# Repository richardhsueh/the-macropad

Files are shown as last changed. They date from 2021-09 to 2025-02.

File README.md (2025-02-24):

# The Macropad

## Overview
A custom design Macropad with 9 buttons
Macropad

## Features
- hot-swappable switches 
- hot-swappable micro controller
- minimal construction for easy repair

## Project Structure
```
project/
├── firmware/          # MCU code if applicable
├── pcb/               # Gerber files for manufacturing the main pcb
└── plate/             # Gerber files for manufacturing the top plate

```

## Requirements
- KiCad 7.0+
- VScode

## Manufacturing
Gerber files are provided in `pcb/` and `plate/`. Recommended fab specs:
- Layers: 2
- Thickness: 1.6mm
- Copper weight: 1oz
- Surface finish: HASL/ENIG

## Assembly
Macropad Assembly

1. Solder the hot-swap sockets to the PCB
2. Insert the switches into the top plate
3. Snap the switches into the hot-swap sockets
4. Insert the microcontroller into the socket
5. Install the spacer and bottom screws
6. Place on the top plate
7. Screw on the top screws

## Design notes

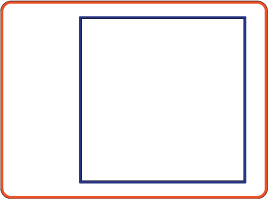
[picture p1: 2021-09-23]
plate/pics/1x/Asset 1.png

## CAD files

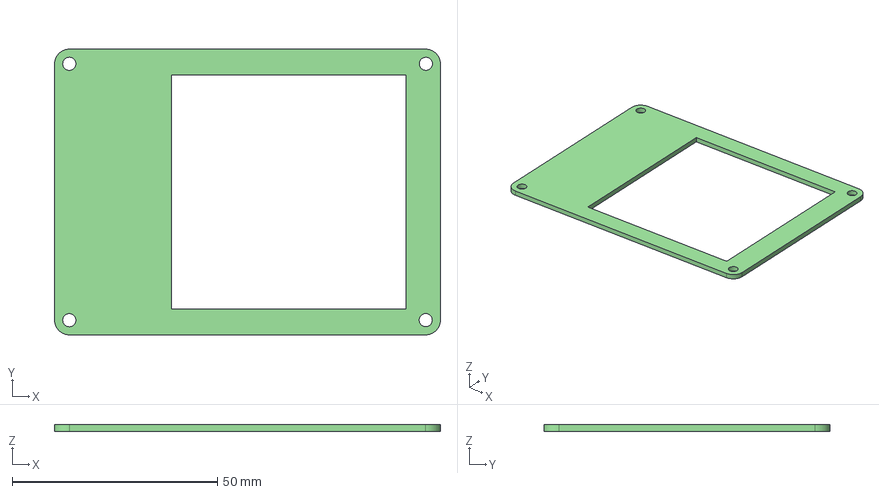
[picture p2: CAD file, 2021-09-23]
plate/SMP top plate v.4 .step
94.1 x 69.7 x 1.60 mm

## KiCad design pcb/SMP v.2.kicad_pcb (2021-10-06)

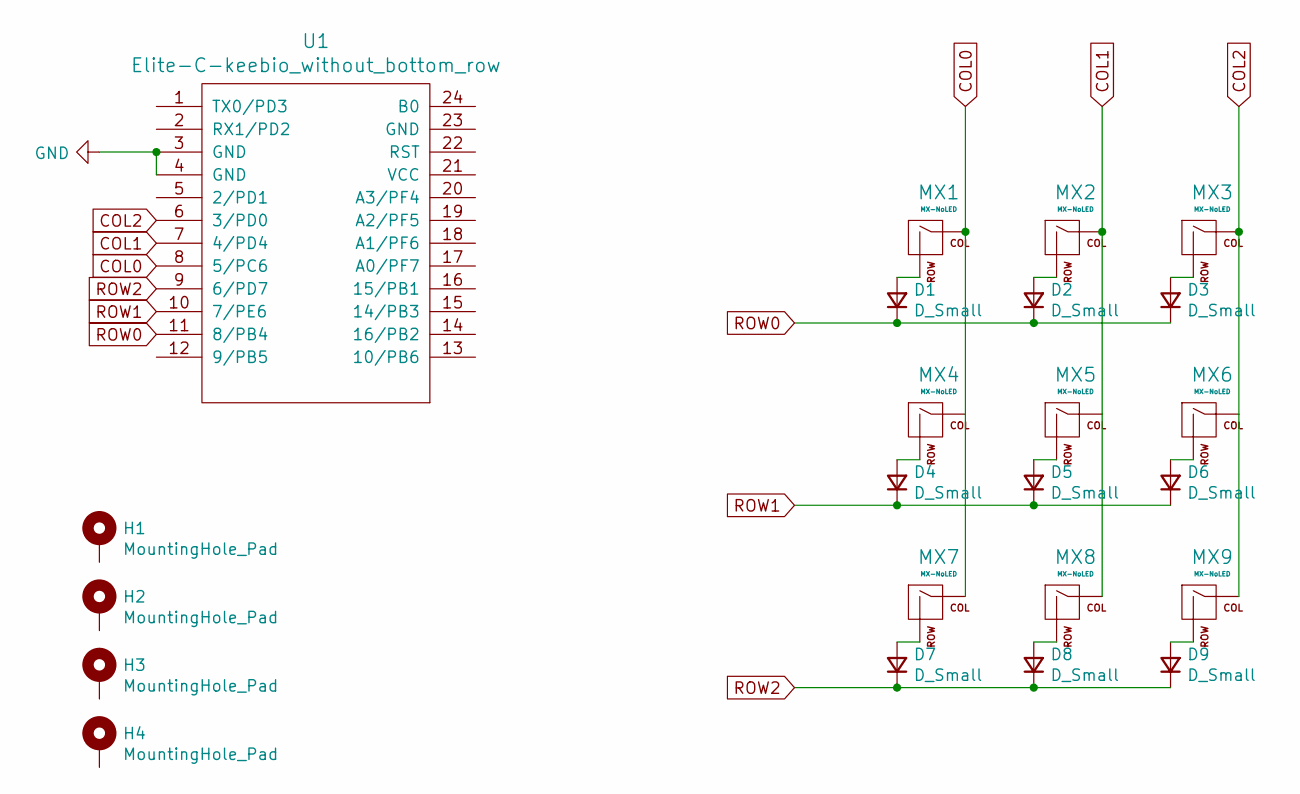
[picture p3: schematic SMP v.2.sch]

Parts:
D1, D2, D3, D4, D5, D6, D7, D8, D9: D_Small; D_DO-35_SOD27_P5.08mm_Horizontal
H1, H2, H3, H4: MountingHole_Pad; MountingHole_3.2mm_M3_Pad
MX1, MX2, MX3, MX4, MX5, MX6, MX7, MX8, MX9: MX-NoLED; MXOnly-1U-Hotswap
U1: Elite-C-keebio_without_bottom_row; Elite-C-ZigZag_no-fsilks

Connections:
COL0: MX1.1 (COL), MX4.1 (COL), MX7.1 (COL), U1.8 (5/PC6)
COL1: MX2.1 (COL), MX5.1 (COL), MX8.1 (COL), U1.7 (4/PD4)
COL2: MX3.1 (COL), MX6.1 (COL), MX9.1 (COL), U1.6 (3/PD0)
GND: U1.3 (GND), U1.4 (GND)
unnamed: D1.2 (A), MX1.2 (ROW)
unnamed: D2.2 (A), MX2.2 (ROW)
unnamed: D3.2 (A), MX3.2 (ROW)
unnamed: D4.2 (A), MX4.2 (ROW)
unnamed: D5.2 (A), MX5.2 (ROW)
unnamed: D6.2 (A), MX6.2 (ROW)
unnamed: D7.2 (A), MX7.2 (ROW)
unnamed: D8.2 (A), MX8.2 (ROW)
unnamed: D9.2 (A), MX9.2 (ROW)
ROW0: D1.1 (K), D2.1 (K), D3.1 (K), U1.11 (8/PB4)
ROW1: D4.1 (K), D5.1 (K), D6.1 (K), U1.10 (7/PE6)
ROW2: D7.1 (K), D8.1 (K), D9.1 (K), U1.9 (6/PD7)

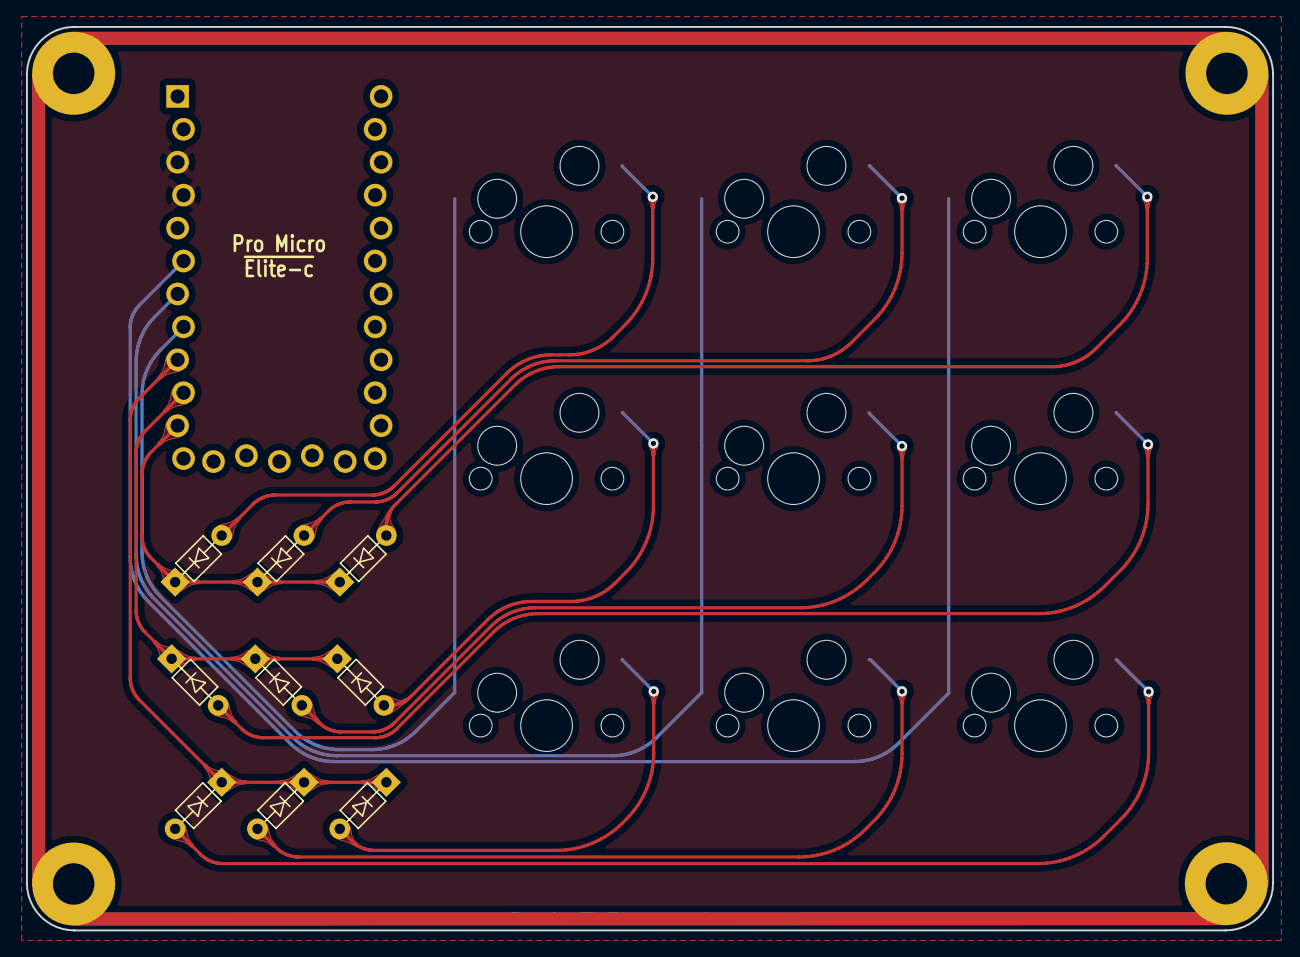
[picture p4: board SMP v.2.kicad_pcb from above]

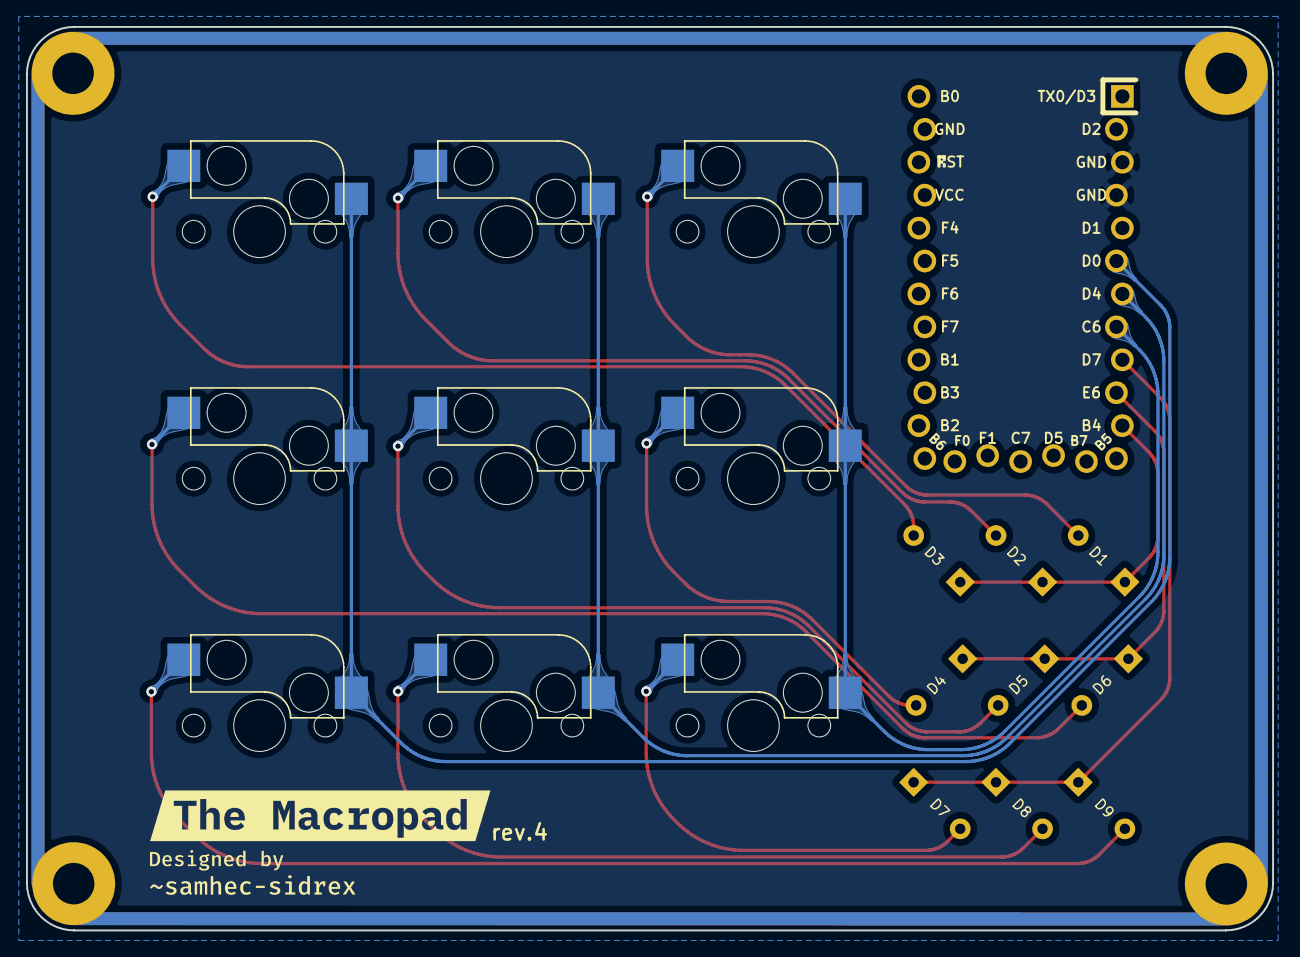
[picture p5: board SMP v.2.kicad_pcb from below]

Board: 2 copper layers, 96.1 x 69.7 mm, 26 parts (3 on the bottom side), 16 nets.

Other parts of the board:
kibuzzard-6147B2C4, kibuzzard-6147B3E3, kibuzzard-6147B285: G***; label

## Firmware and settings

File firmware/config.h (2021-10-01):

#ifndef CONFIG_H
#define CONFIG_H

#include "config_common.h"

/* USB Device descriptor parameter */
#define VENDOR_ID       0xFEED
#define PRODUCT_ID      0x6060
#define DEVICE_VER      0x0001
#define MANUFACTURER    8hands
#define PRODUCT         8hands_smp
#define DESCRIPTION     8hands_smp

/* key matrix size */
#define MATRIX_ROWS 3
#define MATRIX_COLS 3

/* key matrix pins */
#define MATRIX_ROW_PINS { D7, E6, B4 }
#define MATRIX_COL_PINS { C6, D4, D0 }
#define UNUSED_PINS

/* COL2ROW or ROW2COL */
#define DIODE_DIRECTION COL2ROW

/* Set 0 if debouncing isn't needed */
#define DEBOUNCING_DELAY 5

#endif

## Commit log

2021-08-01 update based on 2moon comment
    [SMP v.2.kicad_pcb, SMP v.2.sch]
2021-08-02 include plate and pcb file
    [SMP top plate v.2 .kicad_pcb, SMP top plate v.2 .sch, SMP v.2.kicad_pcb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]
2021-08-02 update plate file
    [SMP top plate v.2 .kicad_pcb, SMP v.2.kicad_pcb]
2021-08-02 add gerbers
    [SMP top plate v.2 .kicad_pcb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]
2021-08-18 fine tune top plate after prototype 1
    [SMP top plate v.2 .kicad_pcb]
2021-08-19 Add BOM and Pos file
    [SMP top plate v.2 .kicad_pcb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]
2021-08-22 tidy up the folder
    [SMP top plate v.2 .kicad_pcb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]
2021-08-25 WIP: on board mcu
    [SMP v.2.kicad_pcb, SMP v.2.sch]
2021-08-26 latest version
    [SMP v.2-B_Cu.gbl, SMP v.2-B_Cu.gbr, SMP v.2-B_Mask.gbr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]
2021-08-26 update top plate
    [SMP top plate v.2 -B_Cu.gbl, SMP top plate v.2 -B_Cu.gbr, SMP top plate v.2 -B_Mask.gbr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]
2021-08-27 refine the routing
    [SMP v.2 BOM.csv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]
2021-08-29 update firmware
    [SMP v.2.csv, SMP v.2.kicad_pcb, SMP v.2.sch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]
2021-08-30 update visual
    [SMP v.2.kicad_pcb]
2021-09-23 pcb and plate finalize for v.4
    [SMP top plate v.2 -B_Cu.gbl, SMP top plate v.2 -B_Cu.gbr, SMP top plate v.2 -B_Mask.gbr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]
2021-09-29 add top plate
    [SMP top plate v.2 -B_Cu.gbl, SMP top plate v.2 -B_Mask.gbs, SMP top plate v.2 -B_SilkS.gbo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]
2021-10-01 update firmware and remove top plate
    [SMPv3.1_BOM.csv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]
2021-10-06 update pcb sch
    [SMP v.2.kicad_pcb, SMP v.2.sch]
2025-02-24 added README and removed outdated data
    [SMP top plate v.2 -B_Cu.gbl, SMP top plate v.2 -B_Mask.gbs, SMP top plate v.2 -B_SilkS.gbo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]
